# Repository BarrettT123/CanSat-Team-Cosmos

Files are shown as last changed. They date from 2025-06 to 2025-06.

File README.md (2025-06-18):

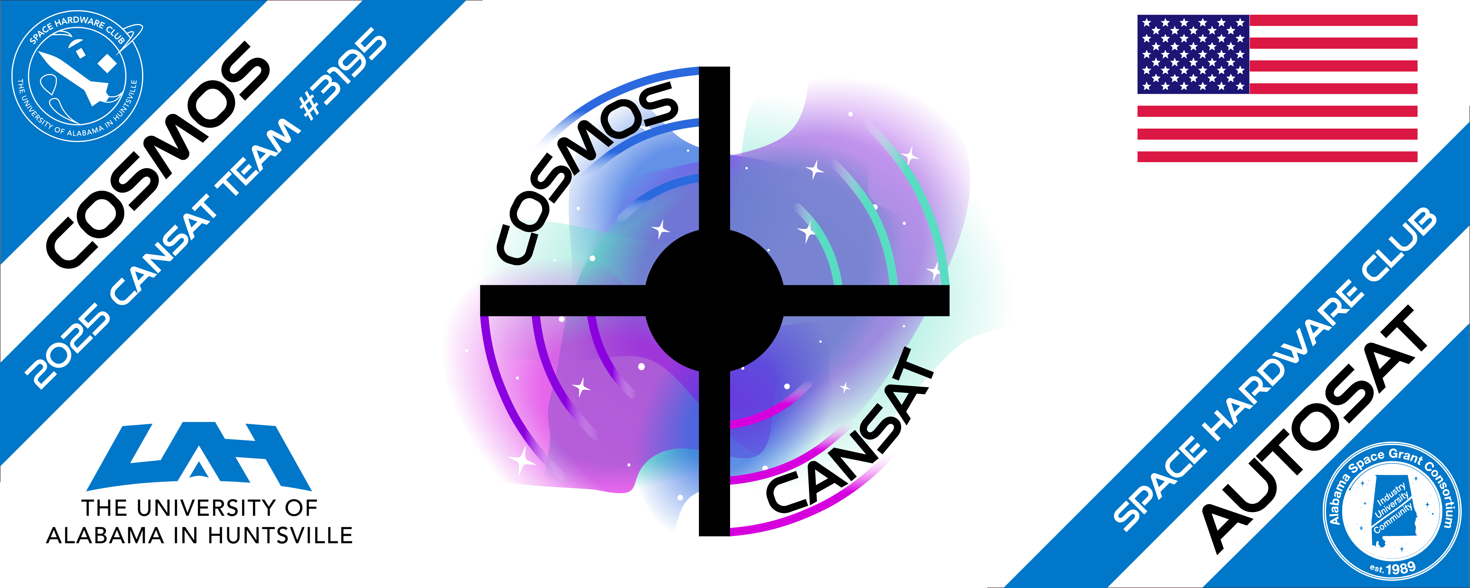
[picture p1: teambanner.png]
banner


(The software I contributed to this project can be found in the CanSat-Team-Cosmos-Software repository)

Cansat Competition Description:
- The Cansat competition is a design-build-fly competition that provides teams with an
opportunity to experience the design life-cycle of an aerospace system. The Cansat
competition is designed to reflect a typical aerospace program on a small scale and includes
all aspects of an aerospace program from the preliminary design review to post flight review.
The mission and its requirements are designed to reflect various aspects of real world
missions including telemetry, communications, and autonomous operations. Each team is
scored throughout the competition on real-world deliverables such as schedules, design
review presentations, and demonstration flights.

Mission Overview:
- Design a Cansat that consists of a payload and a container that mounts on top of the rocket.
The payload rests inside the container at launch and includes the nose cone as part of the
payload.
- The container with the payload shall deploy from the rocket when the rocket reaches peak
altitude and the rocket motor ejection forces a separation. The container with the payload
shall descend at a rate of no more than 20 meters/second using a parachute that
automatically deploys at separation.
- At 75% peak altitude, the payload shall separate from the container and descend using an
auto-gyro descent control system until landing. The descent rate shall be 5 meters/second.
- A video camera shall show the separation of the payload from the container and the auto-gyro
functioning. A second video camera shall be pointing downward at 45 degrees from nadir
and oriented north during descent and be spin stabilized so that the view of the earth is not
rotating.
- The Cansat shall collect sensor data during ascent and descent and transmit the data to a
ground station at a 1 Hz rate. The sensor data shall include interior temperature, battery
voltage, altitude, auto-gyro rotation rate, acceleration, rate, magnetic field, and GPS position.

Post-Flight Cansat Payload:

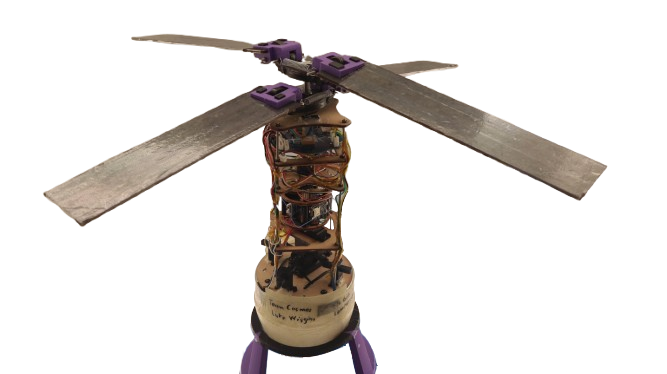
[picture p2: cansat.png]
Cansat


Ground Station during Landing:

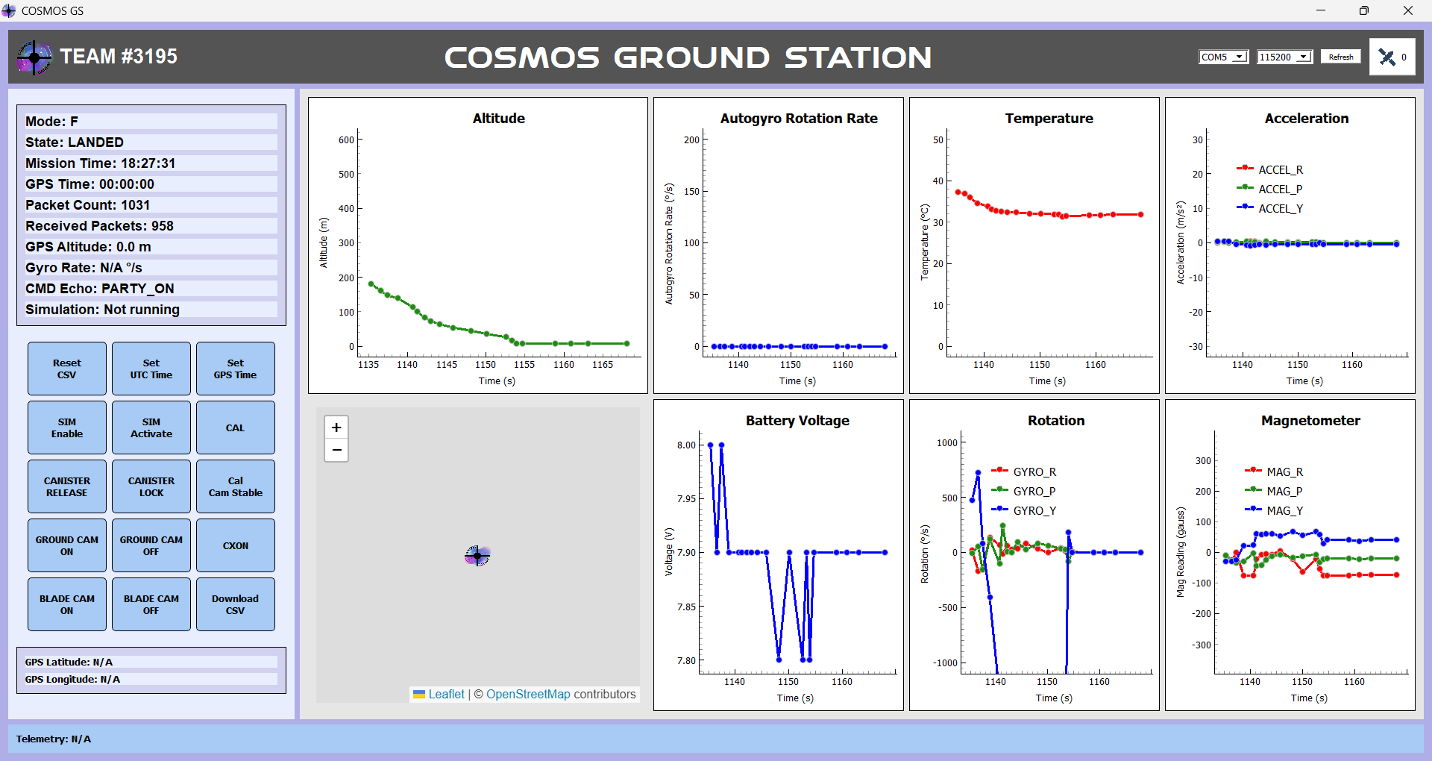
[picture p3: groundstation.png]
Ground Station


Software Contributors:
- `GCS`:
  - Diego Romero-Cardona

- `FSW`:
  - Caleb Wiley
  - Akhil Samiraju
  - Barrett Twining
  - Diego Romero-Cardona

- `PID Board`:
  - Caleb Wiley
  - Barrett Twining
  - Luke Wiggins

Competition Flight Data:
|TEAM_ID|MISSION_TIME|PACKET_COUNT|MODE|STATE |ALTITUDE|TEMPERATURE|PRESSURE|VOLTAGE|GYRO_R |GYRO_P |GYRO_Y  |ACCEL_R|ACCEL_P|ACCEL_Y|MAG_R|MAG_P|MAG_Y|AUTO_GYRO_ROTATION_RATE|GPS_TIME|GPS_ALTITUDE|GPS_LATITUDE|GPS_LONGITUDE|GPS_SATS|CMD_ECHO |TEAM_NAME|
|---|---|---|----|---|---|---|---|---|---|---|---|---|---|---|-----|-----|-----|---|---|---|---|---|---|---|---|
|3195 |18:26:32 |972 |F |LAUNCH_PAD |-0.9 |40.6 |915.5 |7.9 |-0.79  |-1.28  |0.24 |-0.02  |0.00 |-0.49  |-42.6|-3.0 |61.6 |0 |00:00:00|0.0 |0.00000 |0.00000 |0 |ST_UTC_TIME|COSMOS |
|3195 |18:26:33 |973 |F |LAUNCH_PAD |-0.9 |40.7 |915.5 |7.9 |-0.67  |-0.98  |0.37 |-0.02  |-0.00  |-0.49  |-43.5|-2.9 |59.0 |0 |00:00:00|0.0 |0.00000 |0.00000 |0 |ST_UTC_TIME|COSMOS |
|3195 |18:26:38 |978 |F |ASCENT |186.3 |40.7 |895.4 |7.9 |-10.68 |7.63 |-123.54 |-0.10  |-0.05  |-4.00  |-45.7|-7.9 |61.9 |0 |00:00:00|0.0 |0.00000 |0.00000 |0 |ST_UTC_TIME|COSMOS |
|3195 |18:26:39 |979 |F |ASCENT |455.9 |40.6 |867.0 |7.9 |24.29  |-9.09  |-300.78 |-0.12  |0.09 |0.64 |-37.9|-2.8 |63.8 |0 |00:00:00|0.0 |0.00000 |0.00000 |0 |ST_UTC_TIME|COSMOS |
|3195 |18:26:40 |980 |F |ASCENT |478.8 |40.6 |864.7 |7.9 |3.36 |-19.84 |-251.46 |-0.04  |0.14 |0.51 |-33.1|-3.6 |62.0 |0 |00:00:00|0.0 |0.00000 |0.00000 |0 |ST_UTC_TIME|COSMOS |
|3195 |18:26:41 |981 |F |APOGEE |500.4 |40.6 |862.4 |7.9 |-1.53  |-13.43 |-183.53 |0.01 |0.15 |0.31 |-6.4 |-20.7|62.3 |0 |00:00:00|0.0 |0.00000 |0.00000 |0 |ST_UTC_TIME|COSMOS |
|3195 |18:26:42 |982 |F |APOGEE |530.2 |40.5 |859.3 |7.9 |8.67 |-17.94 |-138.37 |-0.02  |0.10 |0.20 |-46.8|-33.5|58.3 |0 |00:00:00|0.0 |0.00000 |0.00000 |0 |ST_UTC_TIME|COSMOS |
|3195 |18:26:43 |983 |F |APOGEE |557.5 |40.5 |856.5 |7.9 |5.19 |-14.28 |-94.97  |-0.02  |0.06 |0.12 |-5.4 |-31.5|58.2 |0 |00:00:00|0.0 |0.00000 |0.00000 |0 |ST_UTC_TIME|COSMOS |
|3195 |18:26:44 |984 |F |APOGEE |579.7 |40.5 |854.3 |7.9 |4.88 |-12.02 |-74.28  |-0.00  |0.03 |0.07 |-32.1|-4.0 |63.1 |0 |00:00:00|0.0 |0.00000 |0.00000 |0 |ST_UTC_TIME|COSMOS |
|3195 |18:26:45 |985 |F |APOGEE |597.4 |40.5 |852.4 |7.9 |1.59 |-8.97  |-56.64  |-0.00  |0.01 |0.03 |-49.3|-27.0|60.7 |0 |00:00:00|0.0 |0.00000 |0.00000 |0 |ST_UTC_TIME|COSMOS |
|3195 |18:26:46 |986 |F |APOGEE |611.3 |40.6 |851.0 |7.9 |-27.71 |-4.70  |-52.43  |-0.00  |-0.03  |0.05 |-36.9|-36.6|62.3 |0 |00:00:00|0.0 |0.00000 |0.00000 |0 |ST_UTC_TIME|COSMOS |
|3195 |18:26:47 |987 |F |APOGEE |616.2 |40.6 |850.5 |7.9 |23.19  |31.19  |-55.60  |0.01 |-0.02  |0.02 |-15.8|-34.8|61.7 |0 |00:00:00|0.0 |0.00000 |0.00000 |0 |ST_UTC_TIME|COSMOS |
|3195 |18:26:48 |988 |F |DESCENT |612.7 |40.6 |850.9 |7.9 |-62.93 |243.71 |-11.78  |0.20 |0.02 |-0.08  |9.2  |-9.7 |-12.0|0 |00:00:00|0.0 |0.00000 |0.00000 |0 |ST_UTC_TIME|COSMOS |
|3195 |18:26:49 |989 |F |DESCENT |603.2 |40.6 |851.9 |7.9 |-166.63|83.56  |115.36  |0.48 |-0.20  |0.09 |3.3  |-28.4|-22.3|0 |00:00:00|0.0 |0.00000 |0.00000 |0 |ST_UTC_TIME|COSMOS |
|3195 |18:26:51 |991 |F |DESCENT |569.9 |40.6 |855.3 |7.9 |355.41 |88.93  |179.75  |0.45 |0.10 |0.11 |-25.0|-19.3|-34.5|0 |00:00:00|0.0 |0.00000 |0.00000 |0 |ST_UTC_TIME|COSMOS |
|3195 |18:26:52 |992 |F |DESCENT |551.7 |40.6 |857.1 |7.9 |20.14  |78.74  |325.38  |-0.07  |0.31 |0.35 |-11.4|9.3  |-19.6|0 |00:00:00|0.0 |0.00000 |0.00000 |0 |ST_UTC_TIME|COSMOS |
|3195 |18:26:53 |993 |F |DESCENT |533.0 |40.6 |859.1 |7.9 |156.19 |229.92 |301.57  |-0.15  |0.42 |0.35 |-12.9|-13.2|-32.8|0 |00:00:00|0.0 |0.00000 |0.00000 |0 |ST_UTC_TIME|COSMOS |
|3195 |18:26:54 |994 |F |DESCENT |510.8 |40.6 |861.4 |7.9 |146.97 |25.39  |286.56  |0.38 |-0.23  |0.42 |2.1  |-38.5|-21.2|0 |00:00:00|0.0 |0.00000 |0.00000 |0 |ST_UTC_TIME|COSMOS |
|3195 |18:26:55 |995 |F |DESCENT |490.6 |40.6 |863.4 |7.9 |-86.98 |-158.63|330.69  |0.14 |0.61 |0.31 |-38.7|3.5  |-26.8|0 |00:00:00|0.0 |0.00000 |0.00000 |0 |ST_UTC_TIME|COSMOS |
|3195 |18:26:56 |996 |F |DESCENT |472.7 |40.6 |865.3 |7.8 |69.27  |195.80 |316.77  |0.37 |0.50 |0.32 |-36.7|3.0  |-26.7|0 |00:00:00|0.0 |0.00000 |0.00000 |0 |ST_UTC_TIME|COSMOS |
|3195 |18:26:57 |997 |F |DESCENT |451.3 |40.6 |867.5 |7.9 |134.70 |77.64  |407.17  |0.46 |0.32 |0.41 |6.7  |-10.9|-18.6|0 |00:00:00|0.0 |0.00000 |0.00000 |0 |ST_UTC_TIME|COSMOS |
|3195 |18:26:58 |998 |F |DESCENT |434.0 |40.6 |869.3 |7.9 |-62.81 |136.17 |393.92  |-0.05  |0.22 |0.41 |-57.7|-2.6 |-18.7|0 |00:00:00|0.0 |0.00000 |0.00000 |0 |ST_UTC_TIME|COSMOS |
|3195 |18:26:59 |999 |F |DESCENT |414.3 |40.6 |871.4 |7.9 |-250.37|206.73 |394.04  |-0.22  |0.51 |0.24 |-26.8|12.5 |-19.1|0 |00:00:00|0.0 |0.00000 |0.00000 |0 |ST_UTC_TIME|COSMOS |
|3195 |18:27:00 |1000 |F |DESCENT |396.6 |40.6 |873.2 |7.9 |-7.32  |90.88  |316.10  |-0.02  |0.25 |0.43 |-58.1|1.8  |-17.3|0 |00:00:00|0.0 |0.00000 |0.00000 |0 |ST_UTC_TIME|COSMOS |
|3195 |18:27:01 |1001 |F |DESCENT |379.0 |40.6 |875.1 |7.9 |-269.53|371.89 |410.64  |-0.24  |0.67 |-0.02  |-29.9|13.9 |-22.2|0 |00:00:00|0.0 |0.00000 |0.00000 |0 |ST_UTC_TIME|COSMOS |
|3195 |18:27:02 |1002 |F |DESCENT |358.8 |40.6 |877.2 |7.8 |-180.79|100.16 |443.54  |-0.40  |0.28 |0.37 |-53.6|6.0  |-18.8|0 |00:00:00|0.0 |0.00000 |0.00000 |0 |ST_UTC_TIME|COSMOS |
|3195 |18:27:03 |1003 |F |PROBE_RELEASE|329.8 |40.4 |880.2 |7.9 |156.86 |-34.48 |512.76  |-0.11  |-0.04  |0.39 |-47.8|-4.9 |-23.5|0 |00:00:00|0.0 |0.00000 |0.00000 |0 |ST_UTC_TIME|COSMOS |
|3195 |18:27:04 |1004 |F |PROBE_RELEASE|306.5 |39.8 |882.7 |7.8 |171.81 |-233.03|429.14  |0.25 |-0.46  |0.24 |-32.3|-46.6|-22.5|0 |00:00:00|0.0 |0.00000 |0.00000 |0 |ST_UTC_TIME|COSMOS |
|3195 |18:27:05 |1005 |F |PROBE_RELEASE|290.9 |39.4 |884.3 |7.9 |195.19 |-323.36|325.81  |0.26 |-0.57  |0.16 |-14.8|-63.6|-2.6 |0 |00:00:00|0.0 |0.00000 |0.00000 |0 |ST_UTC_TIME|COSMOS |
|3195 |18:27:06 |1006 |F |PROBE_RELEASE|275.7 |39.1 |885.9 |7.9 |205.02 |-142.40|310.79  |-0.13  |-0.16  |0.31 |-18.2|-9.4 |-30.4|0 |00:00:00|0.0 |0.00000 |0.00000 |0 |ST_UTC_TIME|COSMOS |
|3195 |18:27:07 |1007 |F |PROBE_RELEASE|256.2 |38.6 |888.0 |7.9 |125.61 |-119.32|473.08  |0.42 |-0.12  |0.36 |-9.1 |-58.5|-6.7 |0 |00:00:00|0.0 |0.00000 |0.00000 |0 |ST_UTC_TIME|COSMOS |
|3195 |18:27:08 |1008 |F |PROBE_RELEASE|238.0 |38.2 |889.9 |7.9 |191.59 |-214.36|288.39  |-0.32  |0.07 |0.37 |-22.8|-3.7 |-29.0|0 |00:00:00|0.0 |0.00000 |0.00000 |0 |ST_UTC_TIME|COSMOS |
|3195 |18:27:09 |1009 |F |PROBE_RELEASE|219.2 |37.8 |891.9 |7.9 |147.58 |15.56  |386.84  |-0.06  |0.00 |0.43 |-22.3|-4.4 |-31.7|0 |00:00:00|0.0 |0.00000 |0.00000 |0 |ST_UTC_TIME|COSMOS |
|3195 |18:27:10 |1010 |F |PROBE_RELEASE|200.3 |37.4 |893.9 |8.0 |131.29 |-99.98 |549.99  |-0.41  |-0.09  |0.40 |-50.2|5.7  |-20.6|0 |00:00:00|0.0 |0.00000 |0.00000 |0 |ST_UTC_TIME|COSMOS |
|3195 |18:27:11 |1011 |F |PROBE_RELEASE|180.6 |37.2 |896.0 |8.0 |18.13  |-7.69  |472.23  |0.04 |0.21 |0.47 |-10.3|-10.8|-28.9|0 |00:00:00|0.0 |0.00000 |0.00000 |0 |ST_UTC_TIME|COSMOS |
|3195 |18:27:12 |1012 |F |PROBE_RELEASE|160.5 |36.9 |898.2 |7.9 |-168.70|52.31  |724.73  |0.42 |0.11 |0.42 |-23.5|-25.8|-30.3|0 |00:00:00|0.0 |0.00000 |0.00000 |0 |ST_UTC_TIME|COSMOS |
|3195 |18:27:13 |1013 |F |PROBE_RELEASE|147.7 |35.9 |899.5 |8.0 |-150.45|-159.18|79.22 |0.09 |-0.11  |0.46 |-1.4 |-33.5|-23.6|0 |00:00:00|0.0 |0.00000 |0.00000 |0 |ST_UTC_TIME|COSMOS |
|3195 |18:27:14 |1014 |F |PROBE_RELEASE|138.8 |34.6 |900.5 |7.9 |137.51 |122.25 |-408.87 |-0.18  |0.10 |-0.44  |-75.2|-29.1|21.8 |0 |00:00:00|0.0 |0.00000 |0.00000 |0 |ST_UTC_TIME|COSMOS |
|3195 |18:27:15 |1015 |F |PROBE_RELEASE|113.2 |33.8 |903.2 |7.9 |64.15  |-101.81|-1292.79|-0.10  |0.34 |-0.60  |-76.4|-3.2 |23.0 |0 |00:00:00|0.0 |0.00000 |0.00000 |0 |ST_UTC_TIME|COSMOS |
|3195 |18:27:16 |1016 |F |PROBE_RELEASE|99.8 |33.1 |904.7 |7.9 |-15.20 |245.54 |-1796.75|0.48 |-0.07  |-0.98  |-22.2|-44.7|60.2 |0 |00:00:00|0.0 |0.00000 |0.00000 |0 |ST_UTC_TIME|COSMOS |
|3195 |18:27:17 |1017 |F |PROBE_RELEASE|83.2 |32.7 |906.5 |7.9 |59.20  |8.79 |-1999.76|0.42 |0.18 |-0.61  |-7.2 |-42.0|57.1 |0 |00:00:00|0.0 |0.00000 |0.00000 |0 |ST_UTC_TIME|COSMOS |
|3195 |18:27:18 |1018 |F |PROBE_RELEASE|72.7 |32.6 |907.6 |7.9 |28.56  |-3.36  |-1999.76|-0.06  |-0.16  |-0.48  |-5.2 |-23.6|60.7 |0 |00:00:00|0.0 |0.00000 |0.00000 |0 |ST_UTC_TIME|COSMOS |
|3195 |18:27:19 |1019 |F |PROBE_RELEASE|63.5 |32.4 |908.6 |7.9 |33.87  |91.13  |-1999.76|-0.17  |0.33 |-0.62  |-6.9 |-12.3|61.6 |0 |00:00:00|0.0 |0.00000 |0.00000 |0 |ST_UTC_TIME|COSMOS |
|3195 |18:27:20 |1020 |F |PROBE_RELEASE|54.1 |32.3 |909.6 |7.9 |79.65  |23.56  |-1999.76|0.05 |0.16 |-0.48  |4.5  |-7.5 |53.2 |0 |00:00:00|0.0 |0.00000 |0.00000 |0 |ST_UTC_TIME|COSMOS |
|3195 |18:27:21 |1021 |F |PROBE_RELEASE|45.0 |32.1 |910.6 |7.8 |30.40  |82.82  |-1999.76|0.24 |0.05 |-0.56  |-23.2|-16.7|68.2 |0 |00:00:00|0.0 |0.00000 |0.00000 |0 |ST_UTC_TIME|COSMOS |
|3195 |18:27:22 |1022 |F |PROBE_RELEASE|35.6 |32.0 |911.6 |7.9 |-2.08  |62.38  |-1999.76|0.10 |0.08 |-0.49  |-63.0|-12.4|55.5 |0 |00:00:00|0.0 |0.00000 |0.00000 |0 |ST_UTC_TIME|COSMOS |
|3195 |18:27:23 |1023 |F |PROBE_RELEASE|26.1 |31.9 |912.6 |7.8 |40.34  |34.42  |-1999.76|0.10 |0.09 |-0.43  |-22.2|-6.5 |66.8 |0 |00:00:00|0.0 |0.00000 |0.00000 |0 |ST_UTC_TIME|COSMOS |
|3195 |18:27:24 |1024 |F |PROBE_RELEASE|16.4 |31.8 |913.7 |7.9 |15.26  |23.68  |-1999.76|0.26 |0.17 |-0.56  |-54.9|-31.0|57.9 |0 |00:00:00|0.0 |0.00000 |0.00000 |0 |ST_UTC_TIME|COSMOS |
|3195 |18:27:25 |1025 |F |PROBE_RELEASE|8.5 |31.3 |914.5 |7.8 |16.97  |-82.09 |181.58  |-0.06  |-0.02  |-0.12  |-76.6|-21.8|29.5 |0 |00:00:00|0.0 |0.00000 |0.00000 |0 |ST_UTC_TIME|COSMOS |
|3195 |18:27:26 |1026 |F |PROBE_RELEASE|8.3 |31.5 |914.6 |7.9 |3.85 |2.87 |-1.89 |-0.33  |-0.01  |-0.37  |-74.8|-20.1|41.1 |0 |00:00:00|0.0 |0.00000 |0.00000 |0 |PARTY_ON |COSMOS |
|3195 |18:27:28 |1028 |F |LANDED |8.1 |31.6 |914.6 |7.9 |-0.67  |0.18 |0.79 |-0.32  |-0.02  |-0.37  |-74.7|-20.5|40.0 |0 |00:00:00|0.0 |0.00000 |0.00000 |0 |PARTY_ON |COSMOS |
|3195 |18:27:29 |1029 |F |LANDED |8.0 |31.7 |914.6 |7.9 |1.04 |-0.79  |-0.67 |-0.33  |-0.01  |-0.37  |-73.7|-21.4|37.4 |0 |00:00:00|0.0 |0.00000 |0.00000 |0 |PARTY_ON |COSMOS |
|3195 |18:27:30 |1030 |F |LANDED |7.9 |31.8 |914.6 |7.9 |-0.37  |1.65 |0.00 |-0.33  |-0.01  |-0.37  |-72.8|-20.6|41.2 |0 |00:00:00|0.0 |0.00000 |0.00000 |0 |PARTY_ON |COSMOS |
|3195 |18:27:31 |1031 |F |LANDED |7.8 |31.9 |914.6 |7.9 |0.12 |1.46 |0.79 |-0.32  |-0.01  |-0.37  |-73.8|-20.1|41.4 |0 |00:00:00|0.0 |0.00000 |0.00000 |0 |PARTY_ON |COSMOS |

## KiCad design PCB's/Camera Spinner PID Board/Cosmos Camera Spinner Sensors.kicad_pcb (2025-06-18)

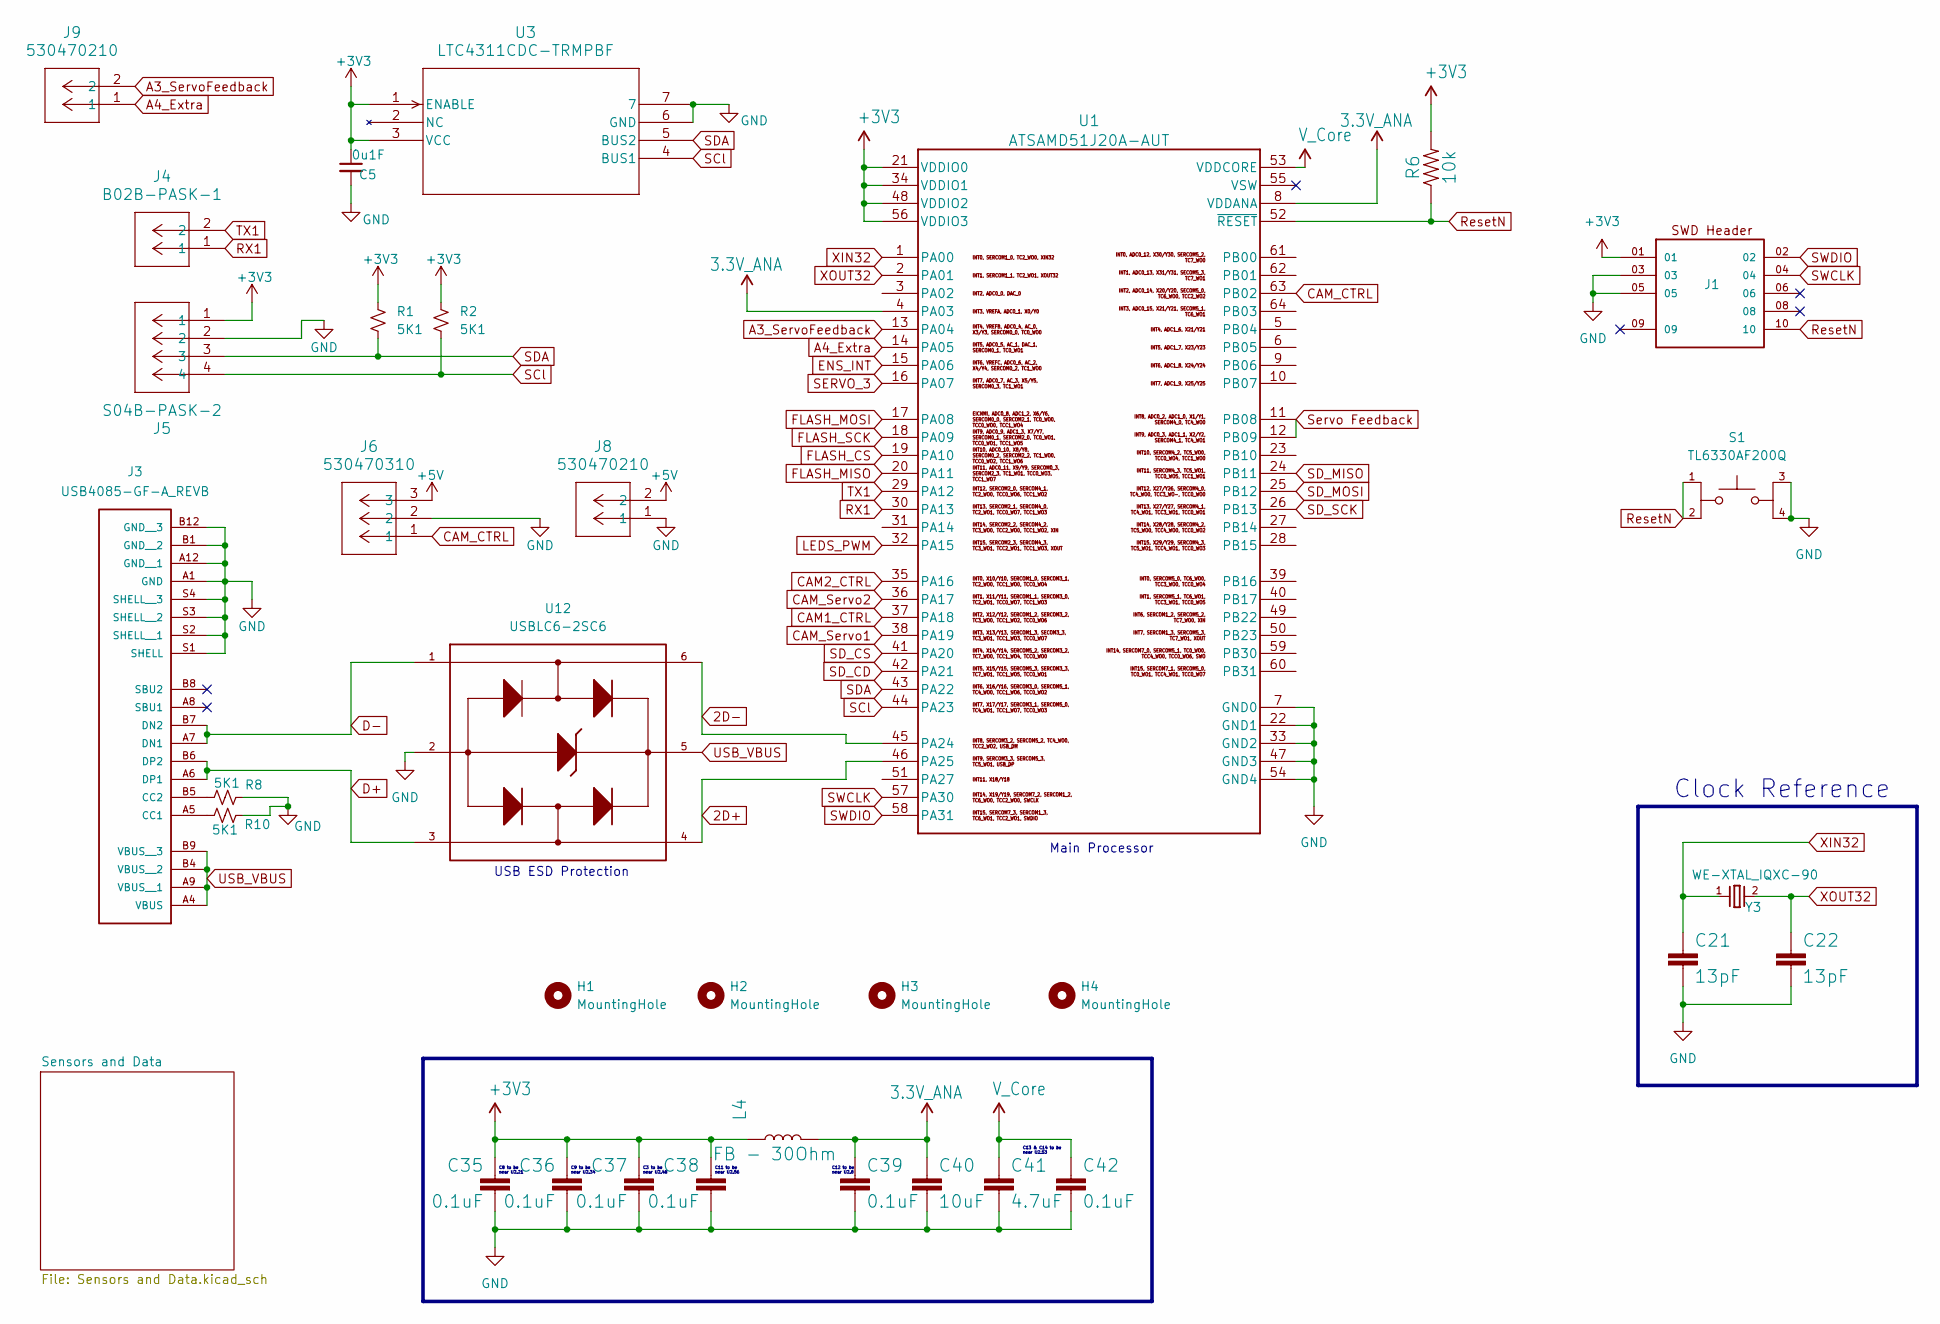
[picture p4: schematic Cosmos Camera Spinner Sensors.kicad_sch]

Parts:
C5: 0u1F; C_0603_1608Metric
C21, C22: 13pF; C_0603_1608Metric
C35, C36, C37, C38, C39, C42: 0.1uF; C_0603_1608Metric
C40: 10uF; C_0603_1608Metric
C41: 4.7uF; C_0603_1608Metric
H1, H2, H3, H4: MountingHole; MountingHole_2.2mm_M2_ISO14580
J1: FTSH-105-X-X-DV-007-P-X; SAMTEC_FTSH-105-X-X-DV-007-P-X
J3: USB4085-GF-A_REVB; GCT_USB4085-GF-A_REVB
J4: B02B-PASK-1; CONN02_530470210_MOL
J5: S04B-PASK-2; CONN4_S04B-PASK_JST
J6: 530470310; CONN03_530470310_MOL
J8, J9: 530470210; CONN02_530470210_MOL
L4: FB - 30Ohm; R_0603_1608Metric
R1, R2, R8, R10: 5K1; R_0603_1608Metric
R6: 10k; R_0603_1608Metric
S1: TL6330AF200Q; SW_TL6330AF200Q
U1: ATSAMD51J20A-AUT; QFN64_9x9MC_MCH_SAMD51J20A_MUT
U3: LTC4311CDC-TRMPBF; DFN-6_DC_LIT
U12: USBLC6-2SC6; USBLC_6
Y3: WE-XTAL_IQXC-90

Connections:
2D+: U1.46 (PA25), U12.4
2D-: U1.45 (PA24), U12.6
3.3V_ANA: C39.1, C40.1, L4.2, U1.4 (PA03), U1.8 (VDDANA)
+3V3: C5.1, C35.1, C36.1, C37.1, C38.1, J1.01, J5.1, L4.1, R1.1, R2.1, R6.2, U1.21 (VDDIO0), U1.34 (VDDIO1), U1.48 (VDDIO2), U1.56 (VDDIO3), U3.1 (ENABLE), U3.3 (VCC); also elsewhere on the board
+5V: J6.3, J8.2
A3_ServoFeedback: J9.2, U1.13 (PA04)
A4_Extra: J9.1, U1.14 (PA05)
CAM1_CTRL: U1.37 (PA18)
CAM2_CTRL: U1.35 (PA16)
CAM_CTRL: J6.1, U1.63 (PB02)
CAM_Servo1: U1.38 (PA19)
CAM_Servo2: U1.36 (PA17)
D+: J3.A6 (DP1), J3.B6 (DP2), U12.3
D-: J3.A7 (DN1), J3.B7 (DN2), U12.1
ENS_INT: U1.15 (PA06); also elsewhere on the board
FLASH_CS: U1.19 (PA10); also elsewhere on the board
FLASH_MISO: U1.20 (PA11); also elsewhere on the board
FLASH_MOSI: U1.17 (PA08); also elsewhere on the board
FLASH_SCK: U1.18 (PA09); also elsewhere on the board
GND: C5.2, C21.2, C22.2, C35.2, C36.2, C37.2, C38.2, C39.2, C40.2, C41.2, C42.2, J1.03, J1.05, J3.A1 (GND), J3.A12 (GND__1), J3.B1 (GND__2), J3.B12 (GND__3), J3.S1 (SHELL), J3.S2 (SHELL__1), J3.S3 (SHELL__2), J3.S4 (SHELL__3), J5.2, J6.2, J8.1, R8.2, R10.2, S1.3, S1.4, U1.7 (GND0), U1.22 (GND1), U1.33 (GND2), U1.47 (GND3), U1.54 (GND4), U1.65, U3.6 (GND), U3.7, U12.2; also elsewhere on the board
LEDS_PWM: U1.32 (PA15)
unnamed: J3.A5 (CC1), R10.1
unnamed: J3.B5 (CC2), R8.1
RX1: J4.1, U1.30 (PA13)
ResetN: J1.10, R6.1, S1.1, S1.2, U1.52 (~RESET)
SCl: J5.4, R2.2, U1.44 (PA23), U3.4 (BUS1); also elsewhere on the board
SDA: J5.3, R1.2, U1.43 (PA22), U3.5 (BUS2); also elsewhere on the board
SD_CD: U1.42 (PA21); also elsewhere on the board
SD_CS: U1.41 (PA20); also elsewhere on the board
SD_MISO: U1.24 (PB11); also elsewhere on the board
SD_MOSI: U1.25 (PB12); also elsewhere on the board
SD_SCK: U1.26 (PB13); also elsewhere on the board
SERVO_3: U1.16 (PA07)
SWCLK: J1.04, U1.57 (PA30)
SWDIO: J1.02, U1.58 (PA31)
Servo Feedback: U1.11 (PB08), U1.12 (PB09)
TX1: J4.2, U1.29 (PA12)
USB_VBUS: J3.A4 (VBUS), J3.A9 (VBUS__1), J3.B4 (VBUS__2), J3.B9 (VBUS__3), U12.5
V_Core: C41.1, C42.1, U1.53 (VDDCORE)
XIN32: C21.1, U1.1 (PA00), Y3.1
XOUT32: C22.1, U1.2 (PA01), Y3.2

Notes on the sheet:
C12 to be near U2.8
C11 to be near U2.56
C13 & C14 to be near U2.53
USB ESD Protection
C9 to be near U2.34
C3 to be near U2.48
Clock Reference
C8 to be near U2.21
Main Processor

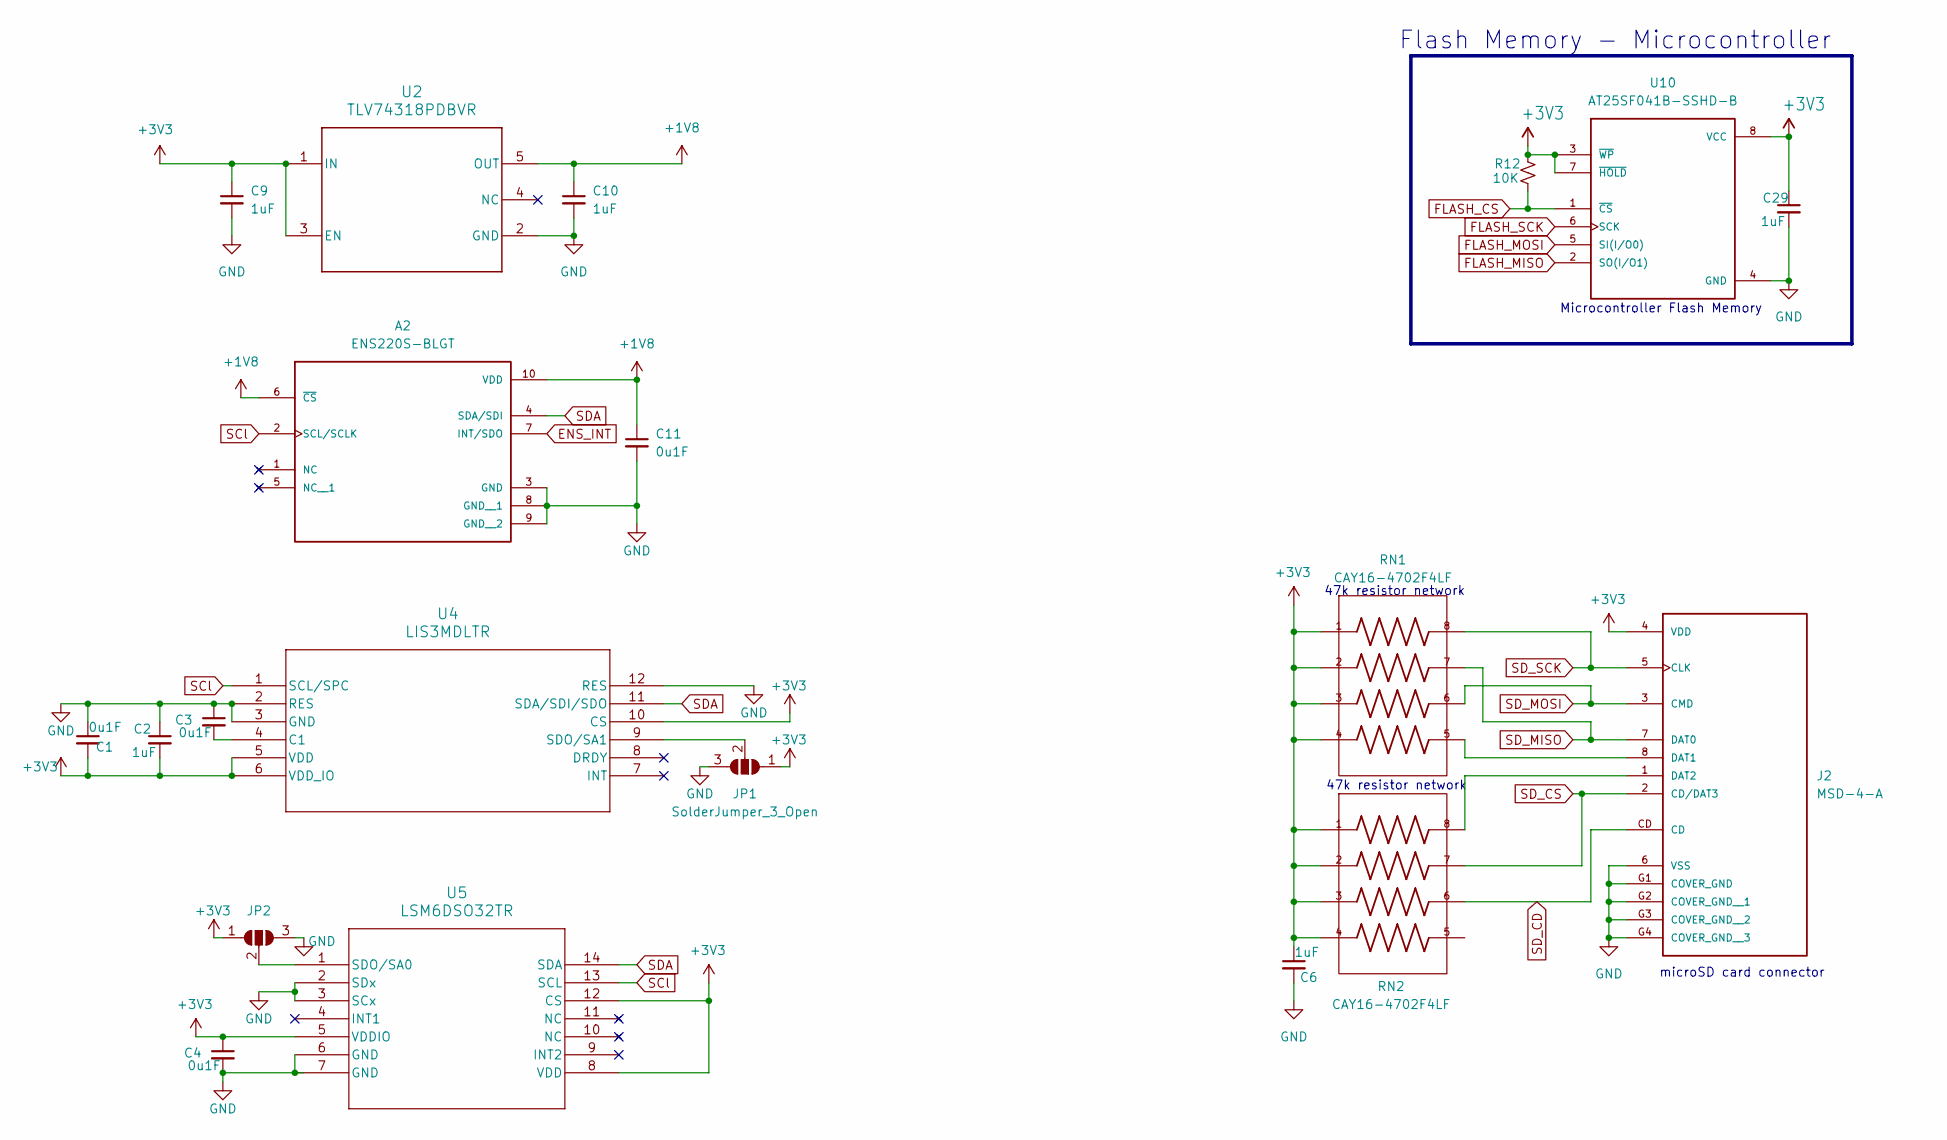
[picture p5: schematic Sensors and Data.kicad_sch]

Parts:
A2: ENS220S-BLGT; XDCR_ENS220S-BLGT
C1, C3, C4, C11: 0u1F; C_0603_1608Metric
C2, C6, C9, C10, C29: 1uF; C_0603_1608Metric
J2: MSD-4-A; CUI_MSD-4-A
JP1, JP2: SolderJumper_3_Open; SolderJumper-3_P1.3mm_Open_RoundedPad1.0x1.5mm
R12: 10K; R_0603_1608Metric
RN1, RN2: CAY16-4702F4LF; CAY16_4702F4LF
U2: TLV74318PDBVR
U4: LIS3MDLTR
U5: LSM6DSO32TR; LSM6DSO
U10: AT25SF041B-SSHD-B; AT25SF041B; PARTREV G

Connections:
+1V8: A2.6 (~CS), A2.10 (VDD), C10.1, C11.1, U2.5 (OUT)
+3V3: C1.2, C2.2, C4.1, C6.1, C9.1, C29.1, J2.4 (VDD), JP1.1 (A), JP2.1 (A), R12.1, RN1.1, RN1.2, RN1.3, RN1.4, RN2.1, RN2.2, RN2.3, RN2.4, U2.1 (IN), U2.3 (EN), U4.5 (VDD), U4.6 (VDD_IO), U4.10 (CS), U5.5 (VDDIO), U5.8 (VDD), U5.12 (CS), U10.3 (~WP), U10.7 (~HOLD), U10.8 (VCC); also elsewhere on the board
ENS_INT: A2.7 (INT/SDO); also elsewhere on the board
FLASH_CS: R12.2, U10.1 (~CS); also elsewhere on the board
FLASH_MISO: U10.2 (SO(I/O1)); also elsewhere on the board
FLASH_MOSI: U10.5 (SI(I/O0)); also elsewhere on the board
FLASH_SCK: U10.6 (SCK); also elsewhere on the board
GND: A2.3 (GND), A2.8 (GND__1), A2.9 (GND__2), C1.1, C2.1, C3.1, C4.2, C6.2, C9.2, C10.2, C11.2, C29.2, J2.6 (VSS), J2.G1 (COVER_GND), J2.G2 (COVER_GND__1), J2.G3 (COVER_GND__2), J2.G4 (COVER_GND__3), JP1.3 (B), JP2.3 (B), U2.2 (GND), U4.2 (RES), U4.3 (GND), U4.12 (RES), U5.2 (SDx), U5.3 (SCx), U5.6 (GND), U5.7 (GND), U10.4 (GND); also elsewhere on the board
unnamed: J2.8 (DAT1), RN1.5
unnamed: J2.1 (DAT2), RN2.8
unnamed: JP1.2 (C), U4.9 (SDO/SA1)
unnamed: JP2.2 (C), U5.1 (SDO/SA0)
unnamed: C3.2, U4.4 (C1)
SCl: A2.2 (SCL/SCLK), U4.1 (SCL/SPC), U5.13 (SCL); also elsewhere on the board
SDA: A2.4 (SDA/SDI), U4.11 (SDA/SDI/SDO), U5.14 (SDA); also elsewhere on the board
SD_CD: J2.CD, RN2.6; also elsewhere on the board
SD_CS: J2.2 (CD/DAT3), RN2.7; also elsewhere on the board
SD_MISO: J2.7 (DAT0), RN1.7; also elsewhere on the board
SD_MOSI: J2.3 (CMD), RN1.6; also elsewhere on the board
SD_SCK: J2.5 (CLK), RN1.8; also elsewhere on the board

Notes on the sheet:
Microcontroller Flash Memory
47k resistor network
microSD card connector
Flash Memory - Microcontroller

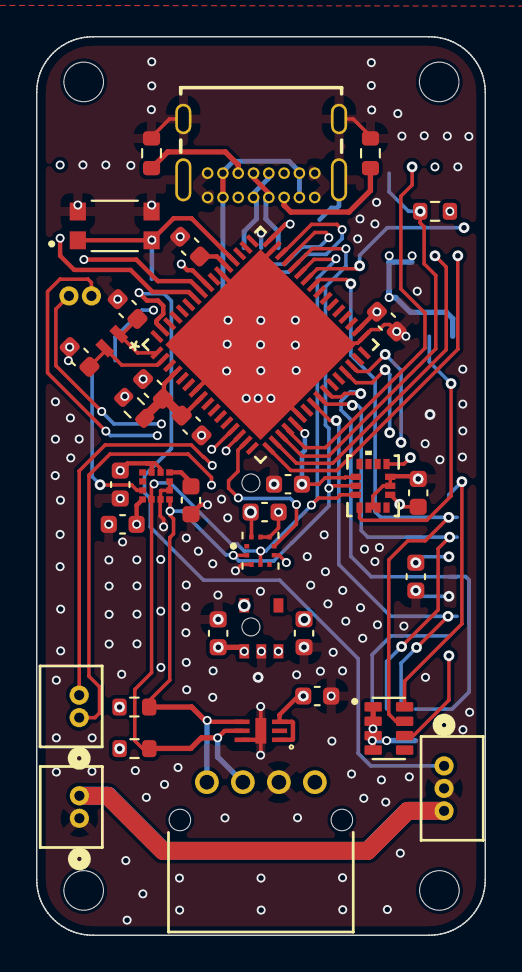
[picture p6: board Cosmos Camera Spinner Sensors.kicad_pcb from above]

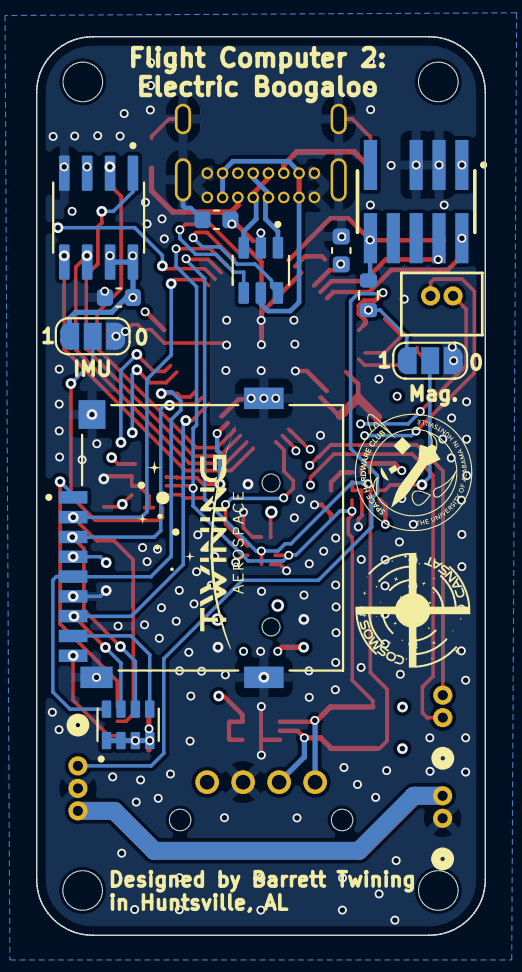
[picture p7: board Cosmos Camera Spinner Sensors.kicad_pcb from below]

Board: 4 copper layers, 24.9 x 49.9 mm, 52 parts (12 on the bottom side), 41 nets.
